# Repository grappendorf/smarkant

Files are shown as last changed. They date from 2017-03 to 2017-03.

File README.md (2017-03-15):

Smarkant - Convert your IKEA Bekant table into an IoT device
============================================================

This work extends the [IKEA-Hackant](https://github.com/robin7331/IKEA-Hackant)
project from [Robin Reiter](https://github.com/robin7331), who reverse engineered
the controller board of an
[IKEA Bekant](http://www.ikea.com/us/en/catalog/products/S59022528) motorized
adjustable table. He added an Arduino board and four buttons to the controller,
so that you can store two table positions and easily recall them.

You can find Robin's work in his
[GitHub repository](https://github.com/robin7331/IKEA-Hackant).
[This Video](https://www.youtube.com/watch?v=AB75AxprXqQ) shows his project
development and the operation of the modified table.

In the Smarkant project i added an ESP-12E to the ATmega328P and communication
between the ESP8266 and the ATmega328P is done through I2C (I first tried to compile
the Arduino code targeting the ESP8266 platform, but since the LIN bus code
directly accesses the ATmega hardware, i've canceled this approach). The ESP8266
gives us WiFi and quite some processing power to implement a REST API to control
our table remotely. This REST interface could be used to implement a smartphone
app or a desktop widget for controlling the table. We could also implement a web
app directly on the ESP8266.

In this project the ESP8266 establishes an MQTT connection to the Amazon IoT
backend and listens for changes to the Smarkant device shadow object.

This project also contains an Alexa skill and an AWS Lamda function that sends
a REST message to the AWS IoT device which in turn sends a message to the table.
This allows us to control the table with voice commands (one can certainly argue
about whether this is more convenient than pressing a button).

The following image shows an overview of this system architecture:

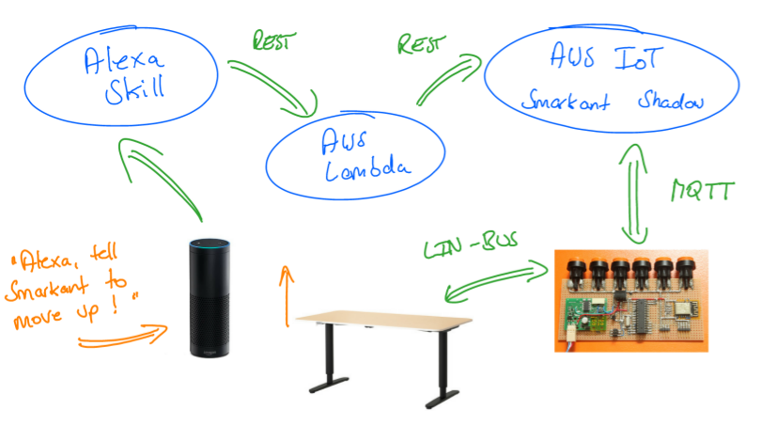
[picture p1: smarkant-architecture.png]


smarkant-arduino
----------------

This directory contains the firmware code for the ATmega328P microcontroller.
The firmware uses the Arduino framework and was developed with the PlatformIO
development environment. It uses the libraries Bounce2 and LinProcessor,
which are contained in the lib sub-directory.

smarkant-esp
------------

This directory contains the firmware code for the ESP8266 (ESP-12E) microcontroller.
The firmware uses the Arduino framework and was developed with the PlatformIO
development environment. It uses the libraries ArduinoJson, AWSSDK, AWSWebSockets,
and Paho MQTTClient, which are contained in the lib sub-directory.

smarkant-alexa
--------------

This directory contains an Alexa skill definition (intent schema and sample
utterances) and a Lambda function, written in JavaScript. The Lambda function
controls the AWS IoT shadow object of the Smarkant thing.

smarkant-kicad
--------------

This directory contains KiCad schematic files for the Smarkant controller.

smarkant-case
-------------

This directory contains 123D Design and STL files of a case for the
Smarkant controller.

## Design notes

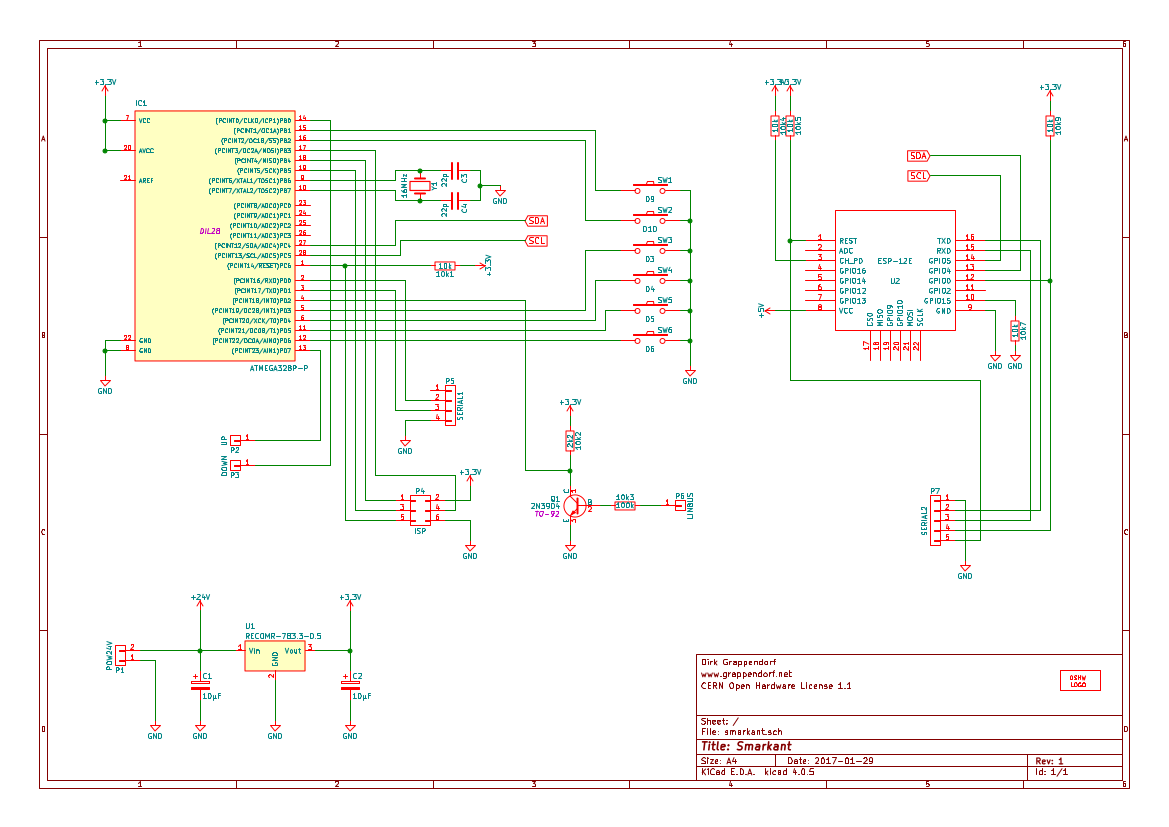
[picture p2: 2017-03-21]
smarkant-kicad/smarkant-sch.png

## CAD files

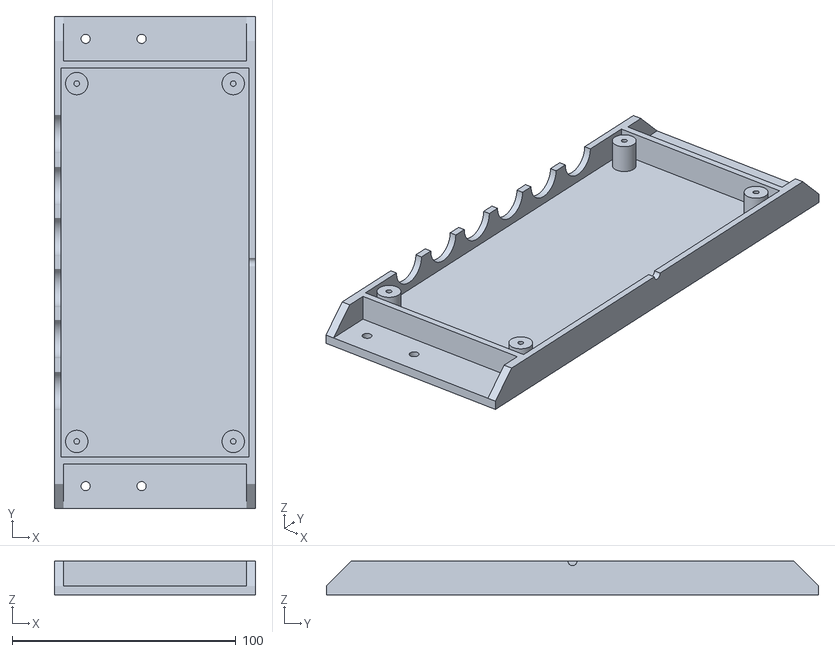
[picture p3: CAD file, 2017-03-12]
smarkant-case/Smarkant Top.stl
90.0 x 220.0 x 15.0

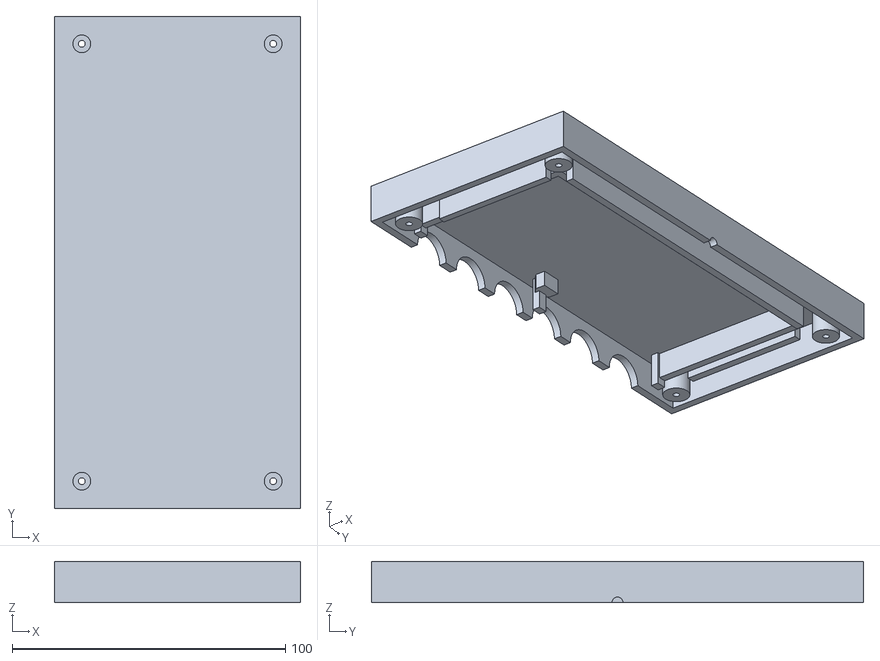
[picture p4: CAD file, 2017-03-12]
smarkant-case/Smarkant Bottom.stl
90.0 x 180.0 x 15.0

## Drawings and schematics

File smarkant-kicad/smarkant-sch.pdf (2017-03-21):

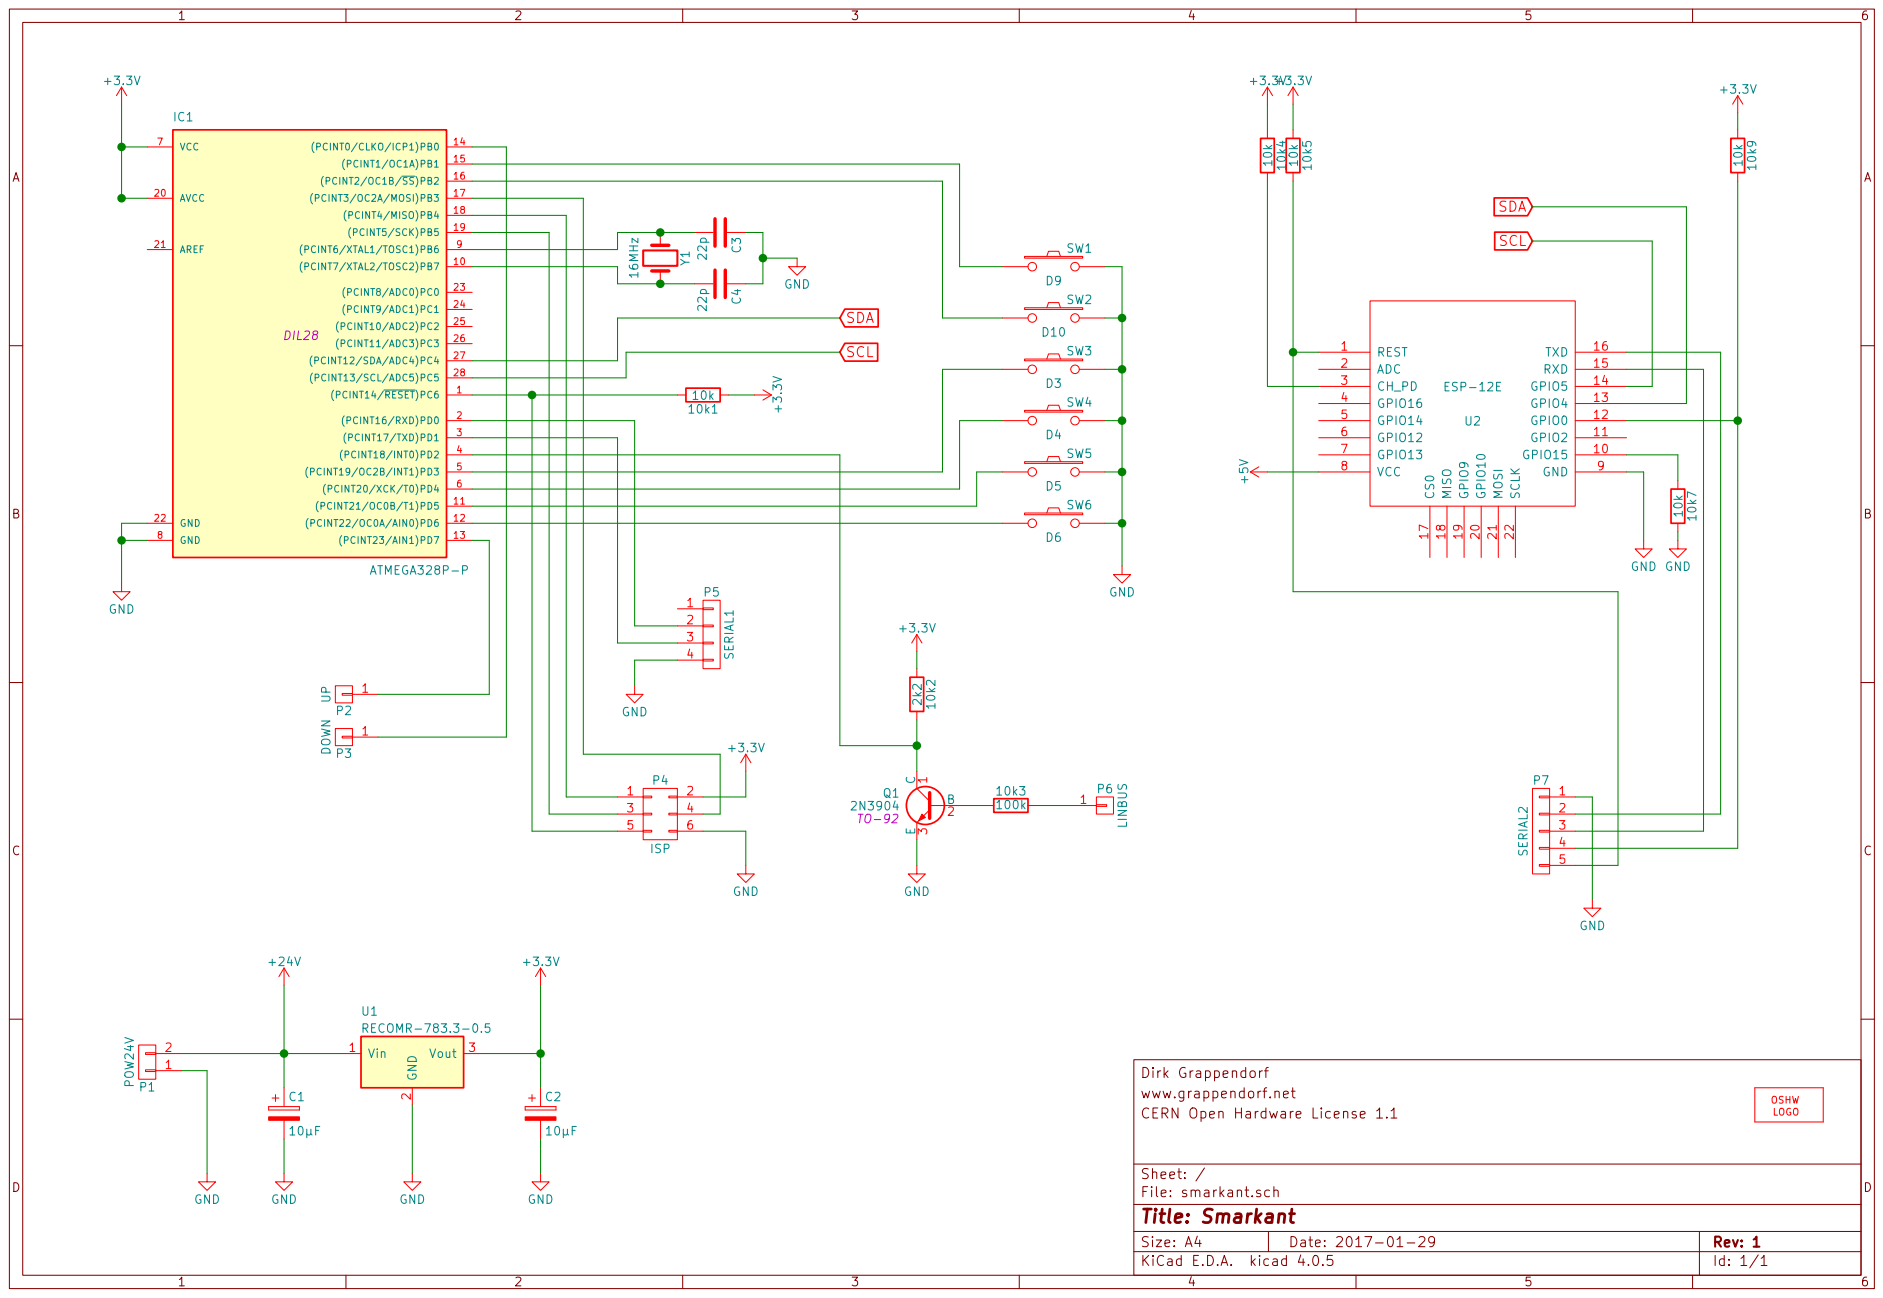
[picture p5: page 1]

2 Vout 3 U1RECOMR-783.3-0.5 GND GND GND GND

www.grappendorf.net
Id: 1/1 Title: Smarkant File: smarkant.sch Sheet: / CERN Open Hardware License 1.1

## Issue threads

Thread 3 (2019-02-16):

Use the same HW setup but fail to detect LINBUS data ...

kimklai, 2019-02-16:
Hi, I love your hacking and try to build an exactly same set.
I'm using ESP12F and Arduino Nano which are pretty the same HW spec as yours as I know...
Everything works fine, except LINBUS.
By using the smarkant-arduino firmware, lin_processor::readNextFrame() just keeps returning false with error code=STOP_BIT.
I'm sure digitalRead(2) continuous reporting 0/1 but lin_processor just failed to decode them.
Is there any key points I'm missing to set/check ?
Anyway to debug the LINBUS issue ?

Thanks

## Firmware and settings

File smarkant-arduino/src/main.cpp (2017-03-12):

/*
 * This file is part of Smarkant project
 *
 * (C) 2017 Dirk Grappendorf, www.grappendorf.net
 *
 * Based on the Hackant project from Robin Reiter
 * https://github.com/robin7331/IKEA-Hackant
 */

#include <Arduino.h>
#include <hardware_clock.h>
#include <system_clock.h>
#include <Wire.h>
#include <EEPROM.h>
#include <Bounce2.h>
#include <lin_processor.h>

const uint8_t BUTTON_UP_PIN = 6;
const uint8_t BUTTON_DOWN_PIN = 5;
const uint8_t BUTTON_POSITION_1_PIN = 4;
const uint8_t BUTTON_POSITION_2_PIN = 3;
const uint8_t BUTTON_POSITION_3_PIN = 10;
const uint8_t BUTTON_POSITION_4_PIN = 9;
const uint8_t TABLE_UP_PIN = 8;
const uint8_t TABLE_DOWN_PIN = 7;
const int NUM_POSITION_BUTTONS = 4;
const uint16_t BUTTON_DEBOUNCE_INTERVAL_MS = 5;
const unsigned long POSITION_BUTTON_STORE_DELAY_MS = 1 * 1000;
const uint16_t HEIGHT_READ_MIN = 100;
const uint16_t HEIGHT_READ_MAX = 8000;
const uint16_t HEIGHT_MIN = 500;
const uint16_t HEIGHT_MAX = 6000;
const uint16_t HEIGHT_DEFAULT = 1200;
const uint16_t HEIGHT_THRESHOLD_MIN = 10;
const uint16_t HEIGHT_THRESHOLD_MAX = 200;
const uint16_t HEIGHT_THRESHOLD_DEFAULT = 50;
const uint8_t I2C_ADDRESS = 0x10;
const unsigned long SERIAL_BAUD_RATE = 115200;
const uint16_t EEPROM_ADDR_HEIGHT_THRESHOLD = 0;
const uint16_t EEPROM_ADDR_POSITIONS = sizeof(uint16_t);
const unsigned long WATCHDOG_INTERVAL_MS = 20 * 1000;
const uint8_t LIN_HEIGHT_FRAME_ID = 0x92;

enum Movement {
  STOP,
  UP,
  DOWN,
  TARGET
};

enum I2CCommand {
  I2C_CMD_NOOP,
  I2C_CMD_MOVE_STOP,
  I2C_CMD_MOVE_UP,
  I2C_CMD_MOVE_DOWN,
  I2C_CMD_MOVE_HEIGHT,
  I2C_CMD_MOVE_POSITION,
  I2C_CMD_STORE_POSITION,
  I2C_CMD_STORE_CURRENT_POSITION,
  I2C_CMD_STORE_THRESHOLD,
  I2C_CMD_READ_HEIGHT,
  I2C_CMD_READ_HEIGHT_THRESHOLD,
  I2C_CMD_READ_POSITIONS
};

Bounce buttonUp = Bounce();
Bounce buttonDown = Bounce();
uint8_t buttonPositionPin[] = {BUTTON_POSITION_1_PIN, BUTTON_POSITION_2_PIN, BUTTON_POSITION_3_PIN, BUTTON_POSITION_4_PIN};
Bounce buttonPosition[] = {Bounce(), Bounce(), Bounce(), Bounce()};
uint16_t positions[] = {0, 0, 0, 0};
uint16_t currentHeight = 0;
uint16_t targetHeight = 0;
uint16_t heightThreshold = 0;
Movement currentMovement = STOP;
unsigned long watchdogTimeout = 0;
unsigned long positionButtonPressTime = 0;
uint8_t i2cReadCommand = I2C_CMD_NOOP;

void watchdogCheck();
void moveTable(Movement move);
void moveTableToHeight(uint16_t height);
void processLINFrame(LinFrame frame);
void storePosition(int index, uint16_t height);
uint16_t recallPosition(int index);
void storeHeightThreshold(uint16_t threshold);
void handleI2CRequest();
void handleI2CReceive(int numBytes);
void loop();
void setup();
void log(const char *str, ...);

void setup() {
  Serial.begin(SERIAL_BAUD_RATE);
  log("Smarkant ready...");

  hardware_clock::setup();
  lin_processor::setup();

  pinMode(BUTTON_UP_PIN, INPUT_PULLUP);
  pinMode(BUTTON_DOWN_PIN, INPUT_PULLUP);
  buttonUp.attach(BUTTON_UP_PIN);
  buttonUp.interval(BUTTON_DEBOUNCE_INTERVAL_MS);
  buttonDown.attach(BUTTON_DOWN_PIN);
  buttonDown.interval(BUTTON_DEBOUNCE_INTERVAL_MS);

  for (int i = 0; i < NUM_POSITION_BUTTONS; ++i) {
    pinMode(buttonPositionPin[i], INPUT_PULLUP);
    buttonPosition[i].attach(buttonPositionPin[i]);
    buttonPosition[i].interval(BUTTON_DEBOUNCE_INTERVAL_MS);
    EEPROM.get(EEPROM_ADDR_POSITIONS + (i * sizeof(uint16_t)), positions[i]);
    if (positions[i] < HEIGHT_MIN || positions[i] > HEIGHT_MAX) {
      log("Storing default position %d", i);
      storePosition(i, HEIGHT_DEFAULT);
    }
  }

  EEPROM.get(EEPROM_ADDR_HEIGHT_THRESHOLD, heightThreshold);
  if (heightThreshold < HEIGHT_THRESHOLD_MIN || heightThreshold > HEIGHT_THRESHOLD_MAX) {
    log("Storing default height threshold");
    storeHeightThreshold(HEIGHT_THRESHOLD_DEFAULT);
  }

  pinMode(TABLE_UP_PIN, INPUT);
  pinMode(TABLE_DOWN_PIN, INPUT);
  digitalWrite(TABLE_UP_PIN, LOW);
  digitalWrite(TABLE_DOWN_PIN, LOW);

  Wire.begin(I2C_ADDRESS);
  Wire.onRequest(handleI2CRequest);
  Wire.onReceive(handleI2CReceive);
}

void loop() {
  watchdogCheck();

  system_clock::loop();
  LinFrame frame;
  if (lin_processor::readNextFrame(&frame)) {
    processLINFrame(frame);
  }

  buttonUp.update();
  buttonDown.update();
  if (buttonUp.rose() || buttonDown.rose()) {
    moveTable(STOP);
  }
  if(buttonUp.fell()) {
    log("Button UP");
    moveTable(currentMovement == STOP ? UP : STOP);
  }
  if(buttonDown.fell()) {
    log("Button DOWN");
    moveTable(currentMovement == STOP ? DOWN : STOP);
  }

  for (int i = 0; i < NUM_POSITION_BUTTONS; ++i) {
    buttonPosition[i].update();
    if(buttonPosition[i].fell()) {
      positionButtonPressTime = millis();
    }
    if(buttonPosition[i].rose()) {
      if (millis() > positionButtonPressTime + POSITION_BUTTON_STORE_DELAY_MS) {
        log("Button POSITION STORE %d", i);
        storePosition(i, currentHeight);
      } else {
        log("Button POSITION RECALL %d", i);
        moveTableToHeight(recallPosition(i));
      }
    }
  }
}

void watchdogCheck() {
  if (currentMovement != STOP && millis() > watchdogTimeout) {
    log("Watchdog timeout");
    moveTable(STOP);
  }
}

void moveTable(Movement move) {
  if (move != STOP) {
    watchdogTimeout = millis() + WATCHDOG_INTERVAL_MS;
  }
  currentMovement = move;
  switch (move) {
    case STOP:
      targetHeight = 0;
      pinMode(TABLE_UP_PIN, INPUT);
      pinMode(TABLE_DOWN_PIN, INPUT);
      break;
    case UP:
      targetHeight = 0;
      pinMode(TABLE_UP_PIN, OUTPUT);
      pinMode(TABLE_DOWN_PIN, INPUT);
      break;
    case DOWN:
      targetHeight = 0;
      pinMode(TABLE_UP_PIN, INPUT);
      pinMode(TABLE_DOWN_PIN, OUTPUT);
      break;
    case TARGET:
      if (targetHeight != 0) {
        if (currentHeight < targetHeight - heightThreshold) {
          pinMode(TABLE_UP_PIN, OUTPUT);
          pinMode(TABLE_DOWN_PIN, INPUT);
        }
        if (currentHeight > targetHeight + heightThreshold) {
          pinMode(TABLE_UP_PIN, INPUT);
          pinMode(TABLE_DOWN_PIN, OUTPUT);
        }
      } else {
        moveTable(STOP);
      }
  }
}

void moveTableToHeight(uint16_t height) {
  if (height < HEIGHT_MIN || height > HEIGHT_MAX) {
    return;
  }
  targetHeight = height;
  moveTable(TARGET);
  log("Moving table to height %d", targetHeight);
}

void processLINFrame(LinFrame frame) {
  uint8_t id = frame.get_byte(0);
  if (id == LIN_HEIGHT_FRAME_ID) {
    uint16_t position = frame.get_byte(2);
    position <<= 8;
    position |= frame.get_byte(1);
    if (position != currentHeight && position >= HEIGHT_READ_MIN && position <= HEIGHT_READ_MAX) {
      currentHeight = position;
      log("Table height: %d", position);
    }

    if (currentMovement == TARGET) {
        if (currentHeight >= targetHeight - heightThreshold &&
            currentHeight <= targetHeight + heightThreshold) {
          moveTable(STOP);
        }
    } else if (currentMovement == UP && currentHeight >= HEIGHT_MAX) {
      moveTable(STOP);
    } else if (currentMovement == DOWN && currentHeight <= HEIGHT_MIN) {
      moveTable(STOP);
    }
  }
}

void storePosition(int index, uint16_t height) {
  if (height >= HEIGHT_MIN || height <= HEIGHT_MAX) {
    log("Store position %d <= %d", index, height);
    EEPROM.put(EEPROM_ADDR_POSITIONS + (index * sizeof(uint16_t)), height);
    positions[index] = height;
  }
}

uint16_t recallPosition(int index) {
  uint16_t height = positions[index];
  log("Recall position %d => %d", index, height);
  return height;
}

void storeHeightThreshold(uint16_t threshold) {
  if (heightThreshold >= HEIGHT_THRESHOLD_MIN || heightThreshold <= HEIGHT_THRESHOLD_MAX) {
    log("Storing height threshold %d", threshold);
    heightThreshold = threshold;
    EEPROM.put(EEPROM_ADDR_HEIGHT_THRESHOLD, threshold);
  }
}

void handleI2CRequest() {
  switch (i2cReadCommand) {
    case I2C_CMD_READ_HEIGHT:
      Wire.write((const uint8_t *) & currentHeight, 2);
      break;
    case I2C_CMD_READ_HEIGHT_THRESHOLD:
      Wire.write((const uint8_t *) & heightThreshold, 2);
      break;
    case I2C_CMD_READ_POSITIONS:
      Wire.write((const uint8_t *) positions, NUM_POSITION_BUTTONS * 2);
      break;
    default:
      break;
  }
}

void handleI2CReceive(int numBytes) {
  uint8_t command = Wire.read();
  switch (command) {
    case I2C_CMD_MOVE_STOP:
      moveTable(STOP);
      break;
    case I2C_CMD_MOVE_UP:
      moveTable(UP);
      break;
    case I2C_CMD_MOVE_DOWN:
      moveTable(DOWN);
      break;
    case I2C_CMD_MOVE_HEIGHT:
      if (numBytes == 3) {
        uint16_t position = Wire.read() + (Wire.read() << 8);
        moveTableToHeight(position);
      }
      break;
    case I2C_CMD_MOVE_POSITION:
      if (numBytes == 2) {
        uint8_t index = Wire.read();
        if (index < NUM_POSITION_BUTTONS) {
          moveTableToHeight(recallPosition(index));
        }
      }
      break;
    case I2C_CMD_STORE_POSITION:
      if (numBytes == 4) {
        uint8_t index = Wire.read();
        if (index < NUM_POSITION_BUTTONS) {
          uint16_t position = Wire.read() + (Wire.read() << 8);
          storePosition(index, position);
        }
      }
      break;
    case I2C_CMD_STORE_CURRENT_POSITION:
      if (numBytes == 2) {
        uint8_t index = Wire.read();
        if (index < NUM_POSITION_BUTTONS) {
          storePosition(index, currentHeight);
        }
      }
      break;
    case I2C_CMD_STORE_THRESHOLD:
      if (numBytes == 3) {
        uint16_t threshold = Wire.read() + (Wire.read() << 8);
        storeHeightThreshold(threshold);
      }
      break;
    case I2C_CMD_READ_HEIGHT:
    case I2C_CMD_READ_HEIGHT_THRESHOLD:
    case I2C_CMD_READ_POSITIONS:
      i2cReadCommand = command;
      break;
    default:
      break;
  }
}

/**
 * https://gist.github.com/asheeshr/9004783
 */
void log(const char *str, ...)
{
  const int LOG_BUFFER_LENGTH = 32;
  int i;
  int j;
  int count = 0;
  for(i = 0; str[i] != '\0'; i++) {
    if(str[i]=='%') {
      count++;
    }
  }
  if (count == 0) {
    Serial.println (str);
    return;
  }
  char temp[LOG_BUFFER_LENGTH + 1];
  va_list argv;
  va_start(argv, str);
  for(i = 0, j = 0; str[i] != '\0'; i++)
  {
    if(str[i] == '%')
    {
      temp[j] = '\0';
      Serial.print(temp);
      j = 0;
      temp[0] = '\0';
      switch(str[++i])
      {
        case 'd':
          Serial.print(va_arg(argv, int));
          break;
        case 'l':
          Serial.print(va_arg(argv, long));
          break;
        case 'f':
          Serial.print(va_arg(argv, double));
          break;
        case 'c':
          Serial.print((char)va_arg(argv, int));
          break;
        case 's':
          Serial.print(va_arg(argv, char *));
          break;
        default:
          break;
      };
    }
    else
    {
      temp[j] = str[i];
      j = (j+1) % LOG_BUFFER_LENGTH;
      if(j==0)
      {
        temp[LOG_BUFFER_LENGTH] = '\0';
        Serial.print(temp);
        temp[0] = '\0';
      }
    }
  };
  Serial.println();
}

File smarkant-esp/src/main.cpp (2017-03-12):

/*
 * This file is part of Smarkant project
 *
 * (C) 2017 Dirk Grappendorf, www.grappendorf.net
 */

#include <Arduino.h>
#include <ESP8266WebServer.h>
#include <ArduinoJson.h>
#include <ESP8266mDNS.h>
#include <ArduinoOTA.h>
#include <Wire.h>
#include <AWSWebSocketClient.h>
#include <IPStack.h>
#include <Countdown.h>
#include <MQTTClient.h>
#include "config.h"

const int PIN_STATUS_LED = 2;
const int JSON_BUFFER_LENGTH = 512;
const int NUM_POSITION_BUTTONS = 4;
const uint16_t HEIGHT_MAX = 6000;
const uint16_t HEIGHT_MIN = 500;
const unsigned long WAIT_FOR_I2C_BYTES_TIMEOUT_MS = 1000;
const uint8_t I2C_ADDRESS = 0x10;
const int WEBSOCKET_PORT = 443;
const int WEBSOCKET_BUFFER_SIZE = 1000;
const int MQTT_MAX_PACKAGE_SIZE = 512;
const int MQTT_MAX_MESSAGE_HANDLERS = 1;
const int MQTT_YIELD_TIMEOUT_MS = 10;
const unsigned long SERIAL_BAUD_RATE = 115200;

enum I2CCommand {
  I2C_CMD_NOOP,
  I2C_CMD_MOVE_STOP,
  I2C_CMD_MOVE_UP,
  I2C_CMD_MOVE_DOWN,
  I2C_CMD_MOVE_HEIGHT,
  I2C_CMD_MOVE_POSITION,
  I2C_CMD_STORE_POSITION,
  I2C_CMD_STORE_CURRENT_POSITION,
  I2C_CMD_STORE_THRESHOLD,
  I2C_CMD_READ_HEIGHT,
  I2C_CMD_READ_HEIGHT_THRESHOLD,
  I2C_CMD_READ_POSITIONS
};

MDNSResponder mdns;
ESP8266WebServer server(80);
AWSWebSocketClient awsIotClient(WEBSOCKET_BUFFER_SIZE);
IPStack mqttIpStack(awsIotClient);
MQTT::Client<IPStack, Countdown, MQTT_MAX_PACKAGE_SIZE, MQTT_MAX_MESSAGE_HANDLERS> *mqttClient = NULL;

void log(const char *str, ...);
void logProgress();
void logProgressEnd();
void setup();
void setupWiFi();
void setupOTA();
void setupWebServer();
void setupAwsIot();
void loop();
bool waitForI2CBytesAvailable(int waitForNumBytess);
bool awsIotConnect ();
void awsIotSubscribeToShadowUpdates();
void awsIotMessageReceived(MQTT::MessageData& message);
void tableStop();
void tableMoveUp();
void tableMoveDown();
void tableMoveToPosition(int position);
void tableMoveToHeight(int height);

void setup() {
  Serial.begin(SERIAL_BAUD_RATE);
  log("Smarkant ready...");

  Wire.begin();

  setupWiFi();
  setupOTA();
  setupWebServer();
  setupAwsIot();
}

void setupWiFi() {
  pinMode(PIN_STATUS_LED, OUTPUT);
  WiFi.begin(WLAN_SSID, WLAN_PASSPHRASE);
  WiFi.mode(WIFI_STA);
  while (WiFi.status() != WL_CONNECTED) {
    digitalWrite(PIN_STATUS_LED, digitalRead(PIN_STATUS_LED) == LOW ? HIGH : LOW);
    delay(100);
  }
  digitalWrite(PIN_STATUS_LED, HIGH);
}

void setupOTA() {
  mdns.begin(HOSTNAME, WiFi.localIP());

  ArduinoOTA.onStart([]() {
    log("OTA update started");
    pinMode(PIN_STATUS_LED, OUTPUT);
  });

  ArduinoOTA.onEnd([]() {
    logProgressEnd();
    log("OTA upate finished");
    digitalWrite(PIN_STATUS_LED, HIGH);
    pinMode(PIN_STATUS_LED, INPUT);
  });

  ArduinoOTA.onProgress([](unsigned int progress, unsigned int total) {
    logProgress();
    digitalWrite(PIN_STATUS_LED, digitalRead(PIN_STATUS_LED) == LOW ? HIGH : LOW);
  });

  ArduinoOTA.onError([](ota_error_t error) {
    logProgressEnd();
    log("OTA upate error");
    digitalWrite(PIN_STATUS_LED, HIGH);
    pinMode(PIN_STATUS_LED, INPUT);
  });

  ArduinoOTA.begin();
}

void loop() {
  ArduinoOTA.handle();
  server.handleClient();
  if (awsIotClient.connected ()) {
     mqttClient->yield(MQTT_YIELD_TIMEOUT_MS);
  } else {
    if (awsIotConnect()){
      awsIotSubscribeToShadowUpdates();
    }
  }
}

void setupWebServer() {
  server.on("/", [](){
    server.send(200, "text/plain", "Hello from Smarkant!");
  });

  server.on("/height", HTTP_GET, [](){
    Wire.beginTransmission(I2C_ADDRESS);
    Wire.write(I2C_CMD_READ_HEIGHT);
    Wire.endTransmission();
    Wire.requestFrom(I2C_ADDRESS, 2);
    if (waitForI2CBytesAvailable(2)) {
      uint16_t height = Wire.read() + (Wire.read() << 8);
      StaticJsonBuffer<JSON_BUFFER_LENGTH> jsonBuffer;
      JsonObject &json = jsonBuffer.createObject();
      json["value"] = height;
      String responseString;
      json.printTo(responseString);
      server.send(200, "application/json", responseString);
    } else {
      server.send(500);
    }
  });

  server.on("/move", HTTP_PUT, [](){
    StaticJsonBuffer<JSON_BUFFER_LENGTH> jsonBuffer;
    JsonObject &json = jsonBuffer.parseObject(server.arg("plain"));
    if (json.success()) {
      if (json.containsKey("height")) {
        tableMoveToHeight((int) json["height"]);
      }
      else if (json.containsKey("position")) {
        tableMoveToPosition((int) json["position"]);
      }
      server.send(204);
    } else {
      server.send(400);
    }
  });

  server.on("/config", HTTP_GET, [](){
    StaticJsonBuffer<JSON_BUFFER_LENGTH> jsonBuffer;
    JsonObject &json = jsonBuffer.createObject();
    Wire.beginTransmission(I2C_ADDRESS);
    Wire.write(I2C_CMD_READ_HEIGHT_THRESHOLD);
    Wire.endTransmission();
    Wire.requestFrom(I2C_ADDRESS, 2);
    if (waitForI2CBytesAvailable(2)) {
      uint16_t threshold = Wire.read() + (Wire.read() << 8);
      json["threshold"] = threshold;
    }
    String responseString;
    json.printTo(responseString);
    server.send(200, "application/json", responseString);
  });

  server.on("/config", HTTP_PUT, [](){
    StaticJsonBuffer<JSON_BUFFER_LENGTH> jsonBuffer;
    JsonObject &json = jsonBuffer.parseObject(server.arg("plain"));
    if (json.success()) {
      if (json.containsKey("threshold")) {
        int threshold = json["threshold"];
        uint8_t data[] = {I2C_CMD_STORE_THRESHOLD, (uint8_t) (threshold & 0xff), (uint8_t) (threshold >> 8)};
        Wire.beginTransmission(I2C_ADDRESS);
        Wire.write(data, 3);
        Wire.endTransmission();
      }
      server.send(204);
    } else {
      server.send(400);
    }
  });

  server.on("/stop", HTTP_PUT, [](){
    tableStop();
    server.send(204);
  });

  server.on("/up", HTTP_PUT, [](){
    tableMoveUp();
    server.send(204);
  });

  server.on("/down", HTTP_PUT, [](){
    tableMoveDown();
    server.send(204);
  });

  server.on("/positions", HTTP_GET, [](){
    Wire.beginTransmission(I2C_ADDRESS);
    Wire.write(I2C_CMD_READ_POSITIONS);
    Wire.endTransmission();
    Wire.requestFrom(I2C_ADDRESS, 2 * NUM_POSITION_BUTTONS);
    if (waitForI2CBytesAvailable(2)) {
      StaticJsonBuffer<JSON_BUFFER_LENGTH> jsonBuffer;
      JsonObject &json = jsonBuffer.createObject();
      uint16_t position = Wire.read() + (Wire.read() << 8);
      json["position0"] = position;
      position = Wire.read() + (Wire.read() << 8);
      json["position1"] = position;
      position = Wire.read() + (Wire.read() << 8);
      json["position2"] = position;
      position = Wire.read() + (Wire.read() << 8);
      json["position3"] = position;
      String responseString;
      json.printTo(responseString);
      server.send(200, "application/json", responseString);
    } else {
      server.send(500);
    }
  });
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

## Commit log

2017-03-12 feat: add KiCad schematics
    [smarkant.kicad_pcb, smarkant.sch]
2017-03-12 feat: add 123d and STL files
    [Smarkant Bottom.stl, Smarkant Top.stl]
2017-03-12 feat: add Arduino firmware files
2017-03-21 fix: power rail is 3.3V instead of 5V
    [smarkant.sch]
